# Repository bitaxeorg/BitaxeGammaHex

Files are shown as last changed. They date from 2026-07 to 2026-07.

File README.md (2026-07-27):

# Bitaxe Gamma Hex

Bitaxe Gamma Hex 1300 is a 6x BM1370 Open Source Bitcoin miner using [esp-miner](https://github.com/bitaxeorg/esp-miner). This project aims to provide a high-performance, energy-efficient Bitcoin mining solution using modern ASIC hardware.

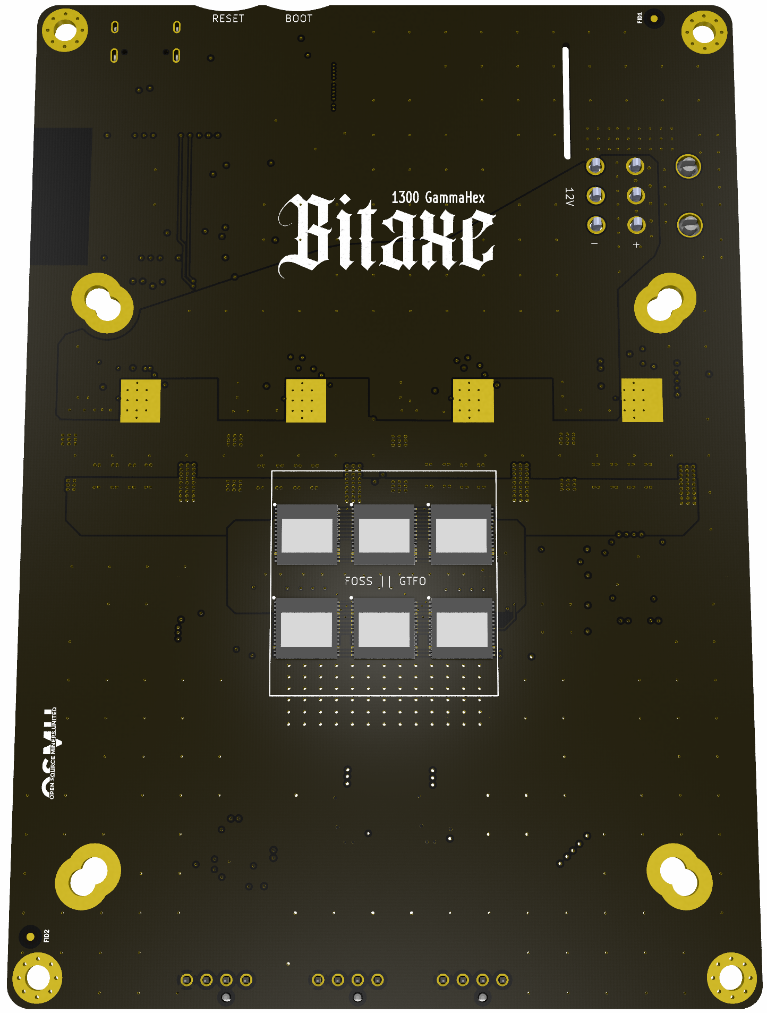
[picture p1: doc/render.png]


## Features

- 1.9 inch color LCD for mining stats.
- ESP32-S3 WiFi microcontroller with full [esp-miner](https://github.com/bitaxeorg/esp-miner) support.
- 12V Input via 6-pin molex.
- Six BM1370 arranged as 2 domains of 3 ASICs ech.
- Four phase TPS546D24S Voltage regulator with adjustable output and live telemetry.
- 12V Bitaxe Accessory Port
- EMC2103 Fan Controller and dual ASIC temp monitor.

## Contributing

BitaxeGammaHex is designed with [KiCad](https://kicad.org) open source PCB design suite. To contribute, follow these steps:

1. Fork the repository.
2. Create a new branch for your feature or bug fix:
   ```bash
   git checkout -b feature/your-feature-name
   ```
3. Make your changes and commit them:
   ```bash
   git commit -m "Add your commit message here"
   ```
4. Push your changes to your fork:
   ```bash
   git push origin feature/your-feature-name
   ```
5. Create a pull request on the main repository.

## License

This project is licensed under the CERN-OHL-2-S License - see the [LICENSE](LICENSE) file for details.

## Acknowledgments

We would like to acknowledge the following projects and individuals for their contributions to the Bitaxe Gamma Hex:

- [esp-miner](https://github.com/bitaxeorg/esp-miner) for the mining firmware.
- The [Open Source Miners United](https://osmu.xyz) community for their support and contributions.

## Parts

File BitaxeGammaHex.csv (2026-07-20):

Reference | Value | Footprint | Datasheet | Qty | PARTNO | Voltage | Exclude from BOM | Exclude from Board
R41,R48,R49,R50,R51,R67 | 0 | Resistor_SMD:R_0402_1005Metric |  | 6 | RC0402JR-070RL
C18,C38,C67,C71 | 33pF | Capacitor_SMD:C_0402_1005Metric | https://datasheets.kyocera-avx.com/C0GNP0-KGM.pdf | 4 | KGM05ACG1E330JH | 25V
C53,C72,C102,C110,C118,C134,C138 | 100pF | Capacitor_SMD:C_0402_1005Metric | https://datasheets.kyocera-avx.com/C0GNP0-KGM.pdf,https://datasheets.kyocera-avx.com/KGM_X7R.pdf | 7 | CC0402JRNPO9BN101 | 50V
C201,C202 | 470pF | Capacitor_SMD:C_0402_1005Metric | https://datasheets.kyocera-avx.com/KGM_X7R.pdf | 2 | GRM1555C1H471JA01D
C17,C37,C65,C68 | 1000pF | Capacitor_SMD:C_0805_2012Metric | https://www.yageo.com/upload/media/product/productsearch/datasheet/mlcc/UPY-GPHC_X7R_6.3V-to-250V_24.pdf | 4 | CC0805KRX7R9BB102 | 50V
C6,C99,C104,C142 | 2.2nF | Capacitor_SMD:C_0402_1005Metric | https://search.murata.co.jp/Ceramy/image/img/A01X/G101/ENG/GRM155R61H222KA01-01.pdf | 4 | GRM155R61H222KA01D | 25V
C5,C95,C101,C107 | 4.7nF | Capacitor_SMD:C_0402_1005Metric | https://search.murata.co.jp/Ceramy/image/img/A01X/G101/ENG/GRM155R71E472KA01-01.pdf | 4 | GRM155R71E472KA01D | 25V
C20,C40 | 33nf | Capacitor_SMD:C_0402_1005Metric |  | 2 | GCM155R71E333KA55D
C16,C36,C39,C64,C66,C83,C84,C203,C205,C206 | 0.1uF | Capacitor_SMD:C_0402_1005Metric | https://datasheets.kyocera-avx.com/KGM_X7R.pdf | 10 | KGM05AR71C104KH
C19,C22,C25,C42,C45,C106,C115,C129,C135,C141 | 100nf | Capacitor_SMD:C_0402_1005Metric |  | 10 | GRM188R61E106KA73D
L1,L2,L3,L4 | 270nH | bitaxe:SLC1175-271MEC_COC |  | 4 | SLC1175-121MEC
C4,C12,C14,C15,C29,C33,C35,C47,C55,C60,C62,C63,C85,C86,C87,C88,C89,C90,C91,C92,C93,C94,C96,C98,C111,C112,C113,C114,C119,C120,C121,C122,C123,C124,C125,C126,C127,C128,C131,C133,C143,C145,C147,C148,C153,C154,C155,C156,C157,C158,C159,C160,C161,C162,C163,C166,C171,C172,C177,C178,C179,C180,C181,C182,C183,C184,C185,C186,C187,C188,C189,C190,C191,C192,C193,C194,C195,C199,C200,C207 | 1uF | Capacitor_SMD:C_0402_1005Metric | https://mm.digikey.com/Volume0/opasdata/d220001/medias/docus/1117/EMK105BJ105MV-F_SS.pdf | 80 | CL05A105KO5NNNC | 25V
L5,L6 | 1.5uH | Inductor_SMD:L_Changjiang_FTC201612S | https://assets.ebee.com/datasheet/2512101426_cjiang-FTC201612S1R5MBCA_C5832350.pdf | 2 | FTC201612S1R5MBCA
C10,C26,C48,C57 | 4.7uF | Capacitor_SMD:C_0402_1005Metric | https://search.murata.co.jp/Ceramy/image/img/A01X/G101/ENG/GRM155R61A475MEAA-01.pdf | 4 | GRM155R61A475MEAAD
C49,C139,C140,C144,C146,C149,C150,C204,C208,C209 | 10uF | Capacitor_SMD:C_0603_1608Metric |  | 10 | GRM188R61E106KA73D | 25V
C7,C8,C9,C11,C13,C21,C23,C24,C27,C30,C41,C43,C44,C46,C50,C51,C52,C56,C58,C61,C77,C79,C97,C100,C108,C109,C116,C117,C130,C132,C136,C137 | 22uF | Capacitor_SMD:C_0805_2012Metric |  | 32 | CL21A226MAQNNNE
C69,C70,C73,C74,C75,C76,C80,C82,C103,C105,C151,C152,C164,C165,C167,C168 | 100uF | Capacitor_SMD:C_1206_3216Metric |  | 16 | CL31A107MQHNNNE | 6.3V
C28,C32 | 220uF | Capacitor_SMD:CP_Elec_8x10 |  | 2 | 118EC427
C31,C54,C78,C81 | 330uF | Capacitor_Tantalum_SMD:CP_EIA-7343-15_Kemet-W |  | 4 | ECG-SY0J331R | 6.3
R6,R9,R18,R19 | 1 | Resistor_SMD:R_0805_2012Metric | https://fscdn.rohm.com/en/products/databook/datasheet/passive/resistor/chip_resistor/esr-e.pdf | 4 | ESR10EZPJ1R0
R5,R8,R16,R17 | 10 | Resistor_SMD:R_0402_1005Metric | https://www.yageo.com/upload/media/product/products/datasheet/rchip/PYu-RC_Group_51_RoHS_L_12.pdf | 4 | RC0402FR-0710RL
R21,R22 | 49.9 | Resistor_SMD:R_0402_1005Metric | https://www.yageo.com/upload/media/product/products/datasheet/rchip/PYu-RC_Group_51_RoHS_L_12.pdf | 2 | RC0402FR-0749R9L
R25,R26,R32,R33,R38,R39,R55,R58,R61,R64,R68,R69,R70,R71,R72 | 1k | Resistor_SMD:R_0402_1005Metric |  | 15 | RC0402FR-071KL
R30,R31,R34,R35,R40 | 2k | Resistor_SMD:R_0402_1005Metric |  | 5 | RC0402FR-072KL
R12,R14,R15 | 4.7k | Resistor_SMD:R_0402_1005Metric |  | 3 | RC0402JR-074K7L
R44,R46 | 5.1k | Resistor_SMD:R_0402_1005Metric |  | 2 | RMCF0402JT5K10
R53 | 5.6k | Resistor_SMD:R_0402_1005Metric |  | 1 | RC0402FR-075K6L
R7,R10,R11,R13,R20,R24,R27,R42,R43,R45,R47,R52,R54,R56,R57,R59,R60,R62,R63,R65,R66,R73,R75,R78 | 10k | Resistor_SMD:R_0402_1005Metric | https://www.yageo.com/upload/media/product/products/datasheet/rchip/PYu-RC_Group_51_RoHS_L_12.pdf | 24 | RC0402DR-0710KL
R76 | 13.7k | Resistor_SMD:R_0402_1005Metric |  | 1 | RMCF0402FT13K7
R23 | 20k | Resistor_SMD:R_0402_1005Metric |  | 1 | RC0402FR-0720KL
R77 | 30.9k | Resistor_SMD:R_0402_1005Metric |  | 1 | RC0402FR-0730K9L
R74 | 52.3k | Resistor_SMD:R_0402_1005Metric |  | 1 | RC0402FR-0752K3L
U8,U9 | 25MHz | Oscillator:Oscillator_SMD_EuroQuartz_XO32-4Pin_3.2x2.5mm |  | 2 | SX3M25.000E20F30THN
U15 | AP2502KTR-G1 | Package_TO_SOT_SMD:SOT-23-6 | https://www.diodes.com/assets/Datasheets/AP2502.pdf | 1 | AP2502KTR-G1
A1,A2,A3,A4,A5,A6 | BM1370 | bitaxe:BM1370 |  | 6 | BM1370
J3,J6,J7 | Conn_01x04 | bitaxe:470531000 |  | 3 | 0470531000
J5 | Conn_02x03_Counter_Clockwise | bitaxe:MOLEX 39301060 |  | 1
U16 | EMC2103-2 | Package_DFN_QFN:QFN-16-1EP_4x4mm_P0.65mm_EP2.1x2.1mm | https://ww1.microchip.com/downloads/en/DeviceDoc/20005250.pdf | 1 | EMC2103-4-AP-TR
U14 | ESP32-S3-WROOM-1 | bitaxe:ESP32-S3-WROOM-1 | https://www.espressif.com/sites/default/files/documentation/esp32-s3-wroom-1_wroom-1u_datasheet_en.pdf | 1 | ESP32-S3-WROOM-1-N16R8
J2 | FPC-05F-30PH20 | bitaxe:FPC-SMD_30P-P0.50_XUNPU_FPC-05F-30PH20 |  | 1 | FPC-05FB-30PH20
U10,U11 | MCP1824T-1202E/OT | Package_TO_SOT_SMD:SOT-23-5 | https://ww1.microchip.com/downloads/en/DeviceDoc/22070a.pdf | 2 | MCP1824T-1202E/OT
U12,U13 | MCP1824T-0802E | Package_TO_SOT_SMD:SOT-23-5 | https://ww1.microchip.com/downloads/en/DeviceDoc/22070a.pdf | 2 | MCP1824T-0802E/OT
U7 | SN74AXC4T774 | Package_SO:TSSOP-16_4.4x5mm_P0.65mm | https://www.ti.com/lit/ds/symlink/sn74axc4t774.pdf | 1 | SN74AXC4T774PWR
SW1,SW2 | SWITCH-SPST | bitaxe:SW_TL3330AF130QG_EWI | https://configured-product-images.s3.amazonaws.com/Datasheets/TL3330.pdf | 2 | TL3330AF130QG
U17 | TLV3544 | Package_SO:TSSOP-14_4.4x5mm_P0.65mm | https://www.ti.com/lit/ds/symlink/tlv3542.pdf | 1 | TLV3544IPWR
U18,U19 | TPS62933 | Package_TO_SOT_SMD:SOT-583-8 | https://www.ti.com/lit/ds/symlink/tps62933.pdf | 2 | TPS62933DRLR
U3,U4,U5,U6 | TPS546D24S | bitaxe:LQFN40-CLIP | https://www.ti.com/lit/ds/symlink/tps546d24a.pdf | 4 | TPS546D24SRVFR
J1 | USB_C_Receptacle_USB2.0 | bitaxe:USB_C_Receptacle_GCT_USB4105-xx-A | https://www.usb.org/sites/default/files/documents/usb_type-c.zip | 1 | USB4105-GF-A

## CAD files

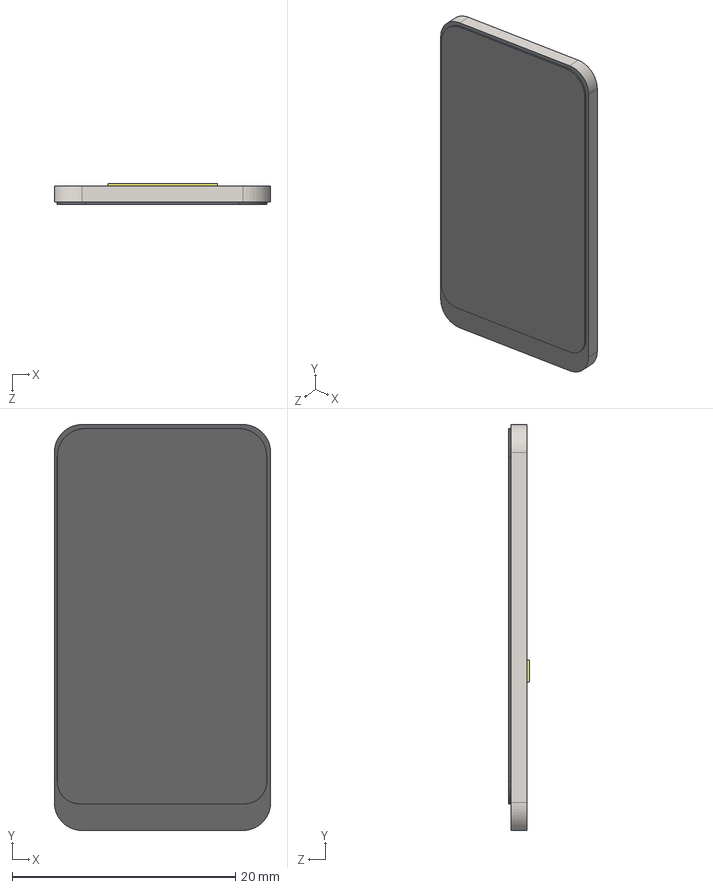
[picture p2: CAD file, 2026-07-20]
3d/DISST7789-176x320.STEP
19.4 x 36.4 x 1.86 mm

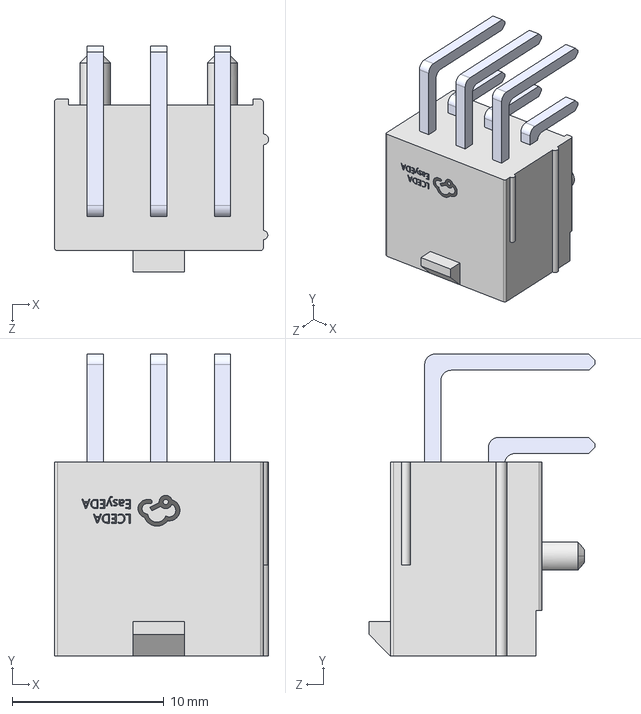
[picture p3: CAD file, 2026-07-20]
3dshapes/CONN-TN_39301060.step
14.2 x 19.9 x 14.9 mm

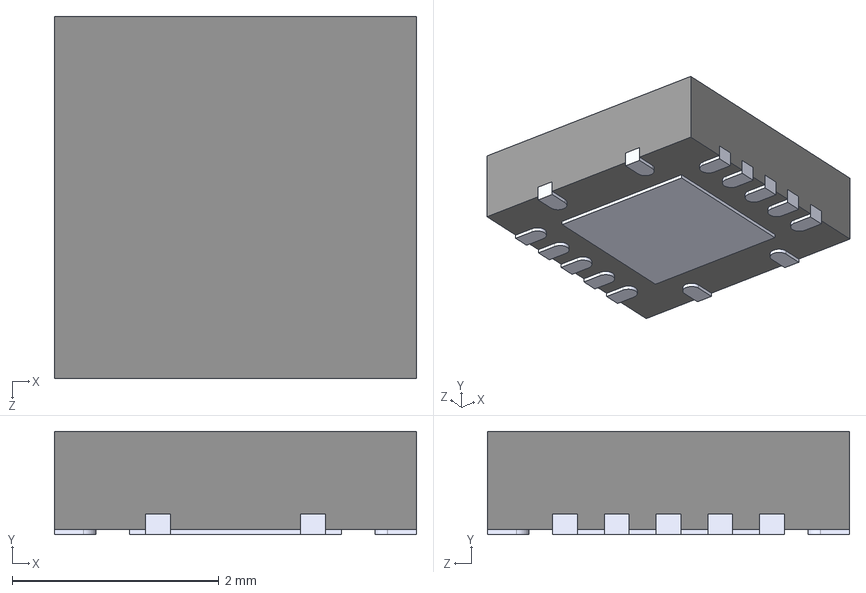
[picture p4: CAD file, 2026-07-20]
3d/TXB0104RGYR.STEP
3.50 x 1.00 x 3.50 mm

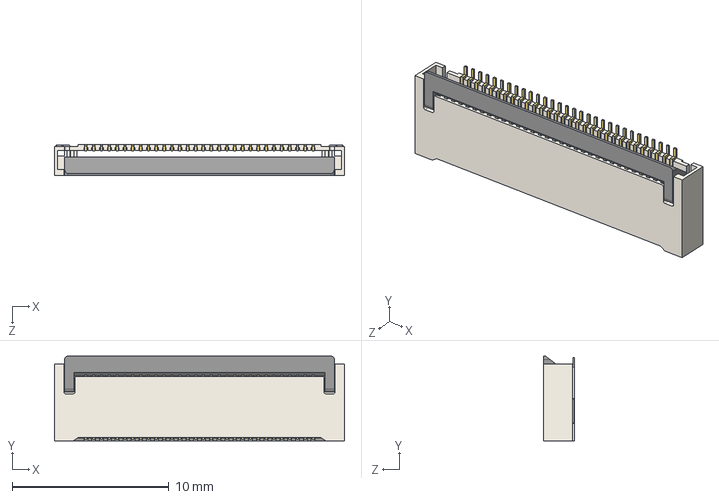
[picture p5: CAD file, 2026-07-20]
3dshapes/FPC-SMD_30P-P0.50_FPC-05FB-30PH20.step
18.5 x 5.40 x 2.00 mm

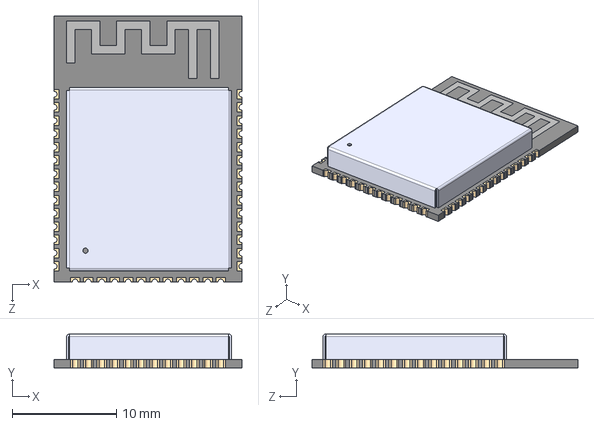
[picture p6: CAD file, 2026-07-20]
3d/ESP32-S3-WROOM-1-N8R2--3DModel-STEP-56544.STEP
18.0 x 3.25 x 25.5 mm

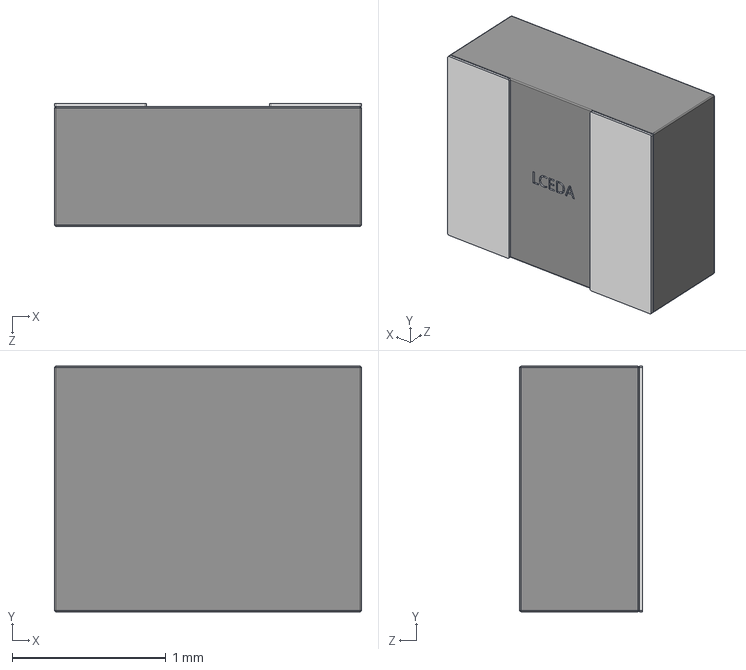
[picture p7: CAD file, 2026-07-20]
3dshapes/IND-SMD_L2.0-W1.6-B.step
2.00 x 1.60 x 0.8 mm

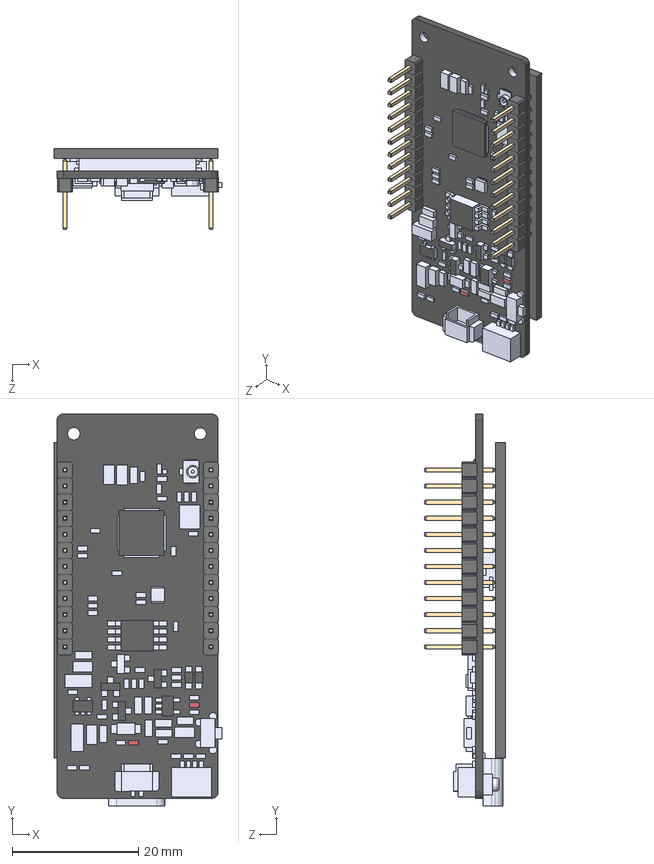
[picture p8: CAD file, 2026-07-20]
3d/T-Display-S3.STEP
26.5 x 62.0 x 12.9 mm
MainBoard_3D
Ecran
1_Male_Pin_2.54_mm x 24

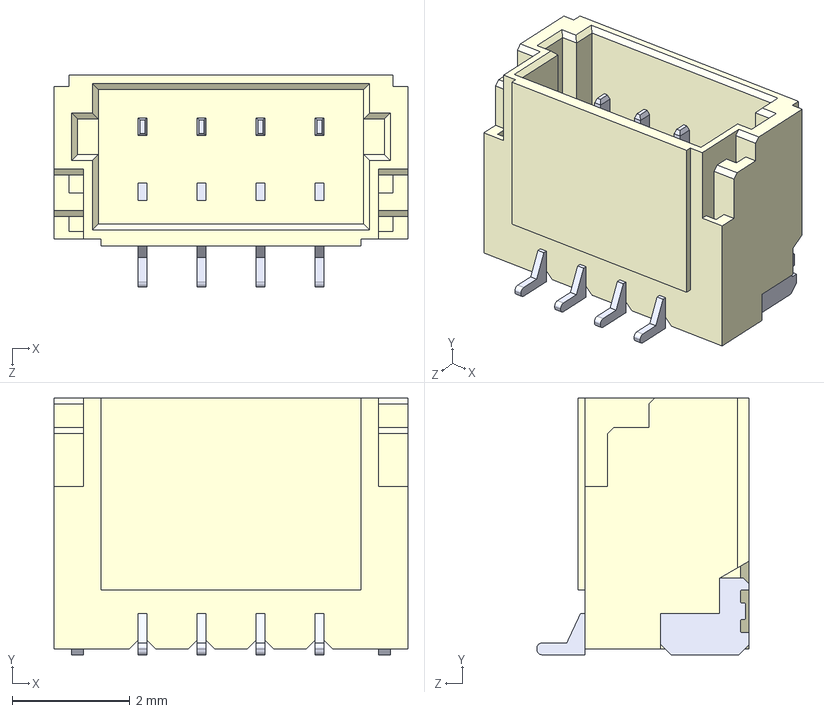
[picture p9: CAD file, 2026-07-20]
3d/BM04B-SRSS-TBT(LF)(SN)--3DModel-STEP-56544.STEP
6.00 x 4.35 x 3.60 mm

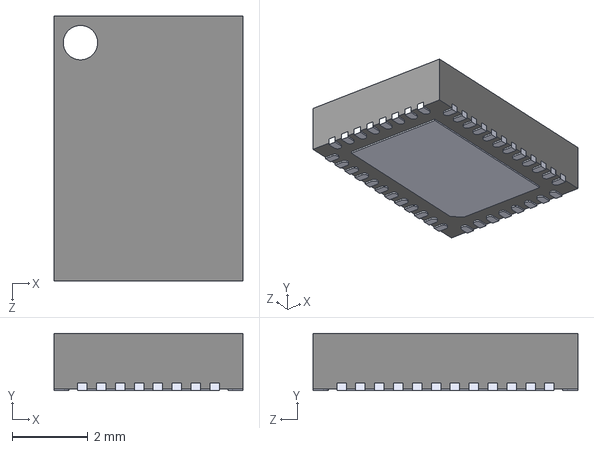
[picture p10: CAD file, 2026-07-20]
3d/TPS546D24ARVFR.step
5.00 x 1.52 x 7.00 mm

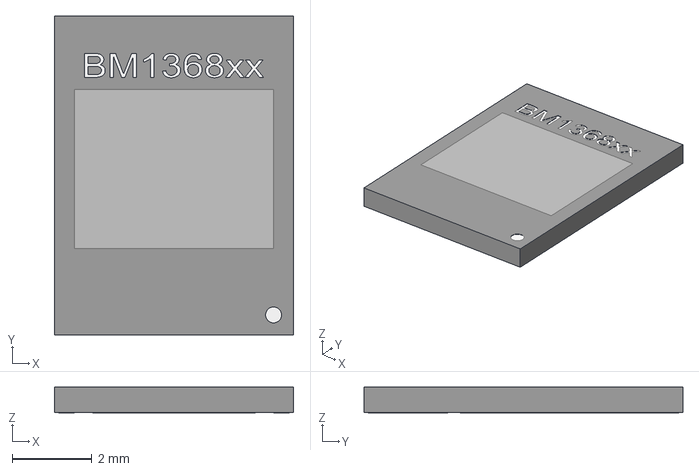
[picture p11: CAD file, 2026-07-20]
3d/BM1368xx.stp
6.00 x 8.00 x 0.65 mm

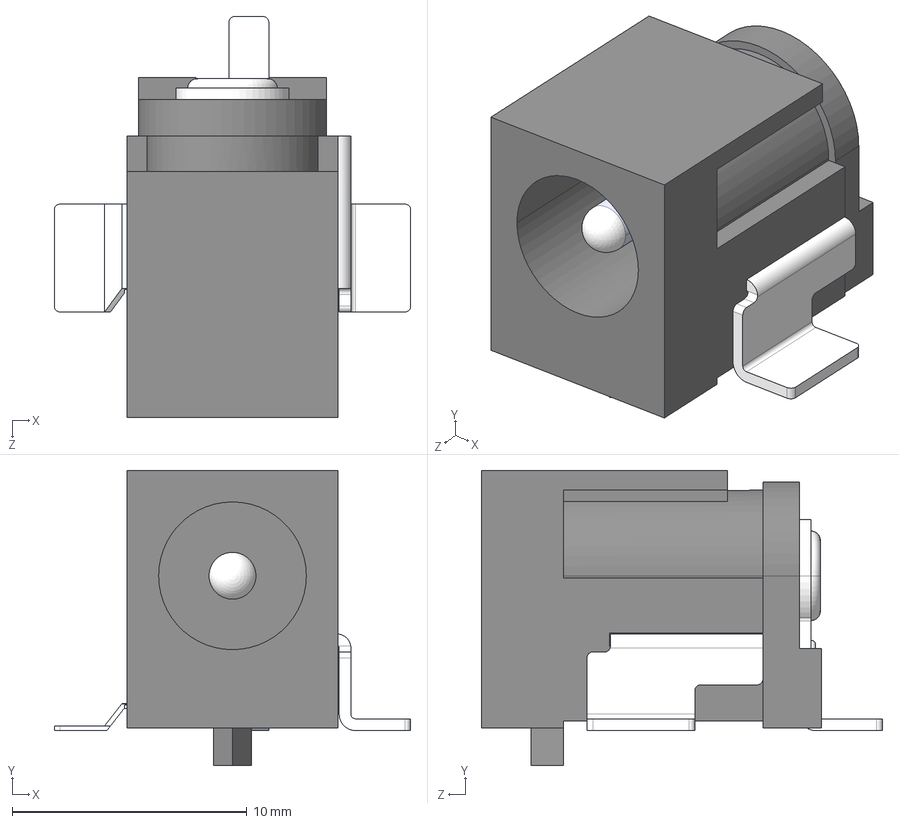
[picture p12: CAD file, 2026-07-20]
3d/CUI_DEVICES_PJ-036AH-SMT-TR.step
15.2 x 12.6 x 17.1 mm

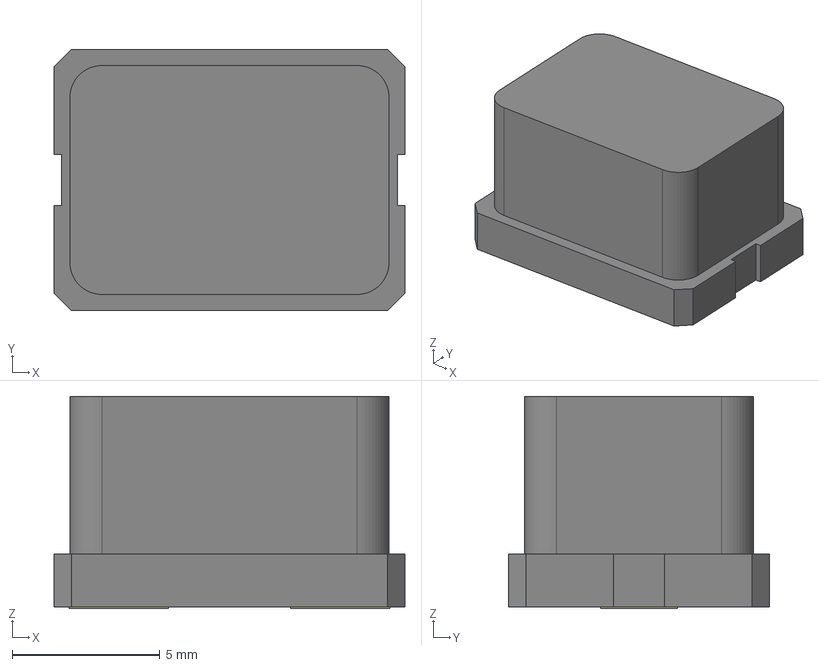
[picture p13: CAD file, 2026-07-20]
3d/SLC1175-271MEC_COC.step
11.9 x 8.83 x 7.19 mm

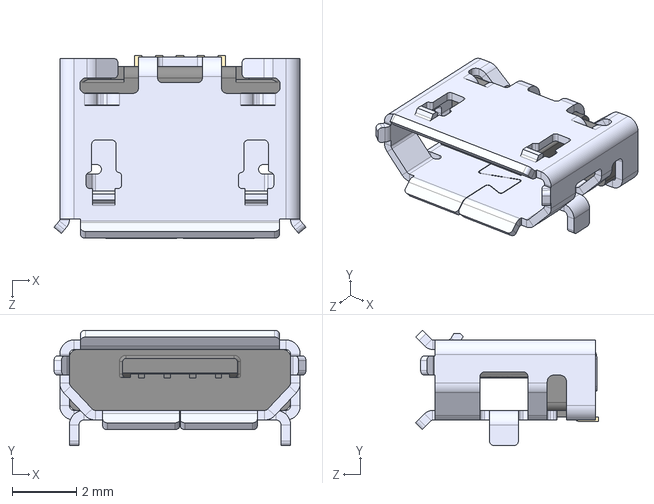
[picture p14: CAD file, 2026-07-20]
3d/USB_10118193-0001LF.STEP
7.86 x 3.60 x 5.71 mm

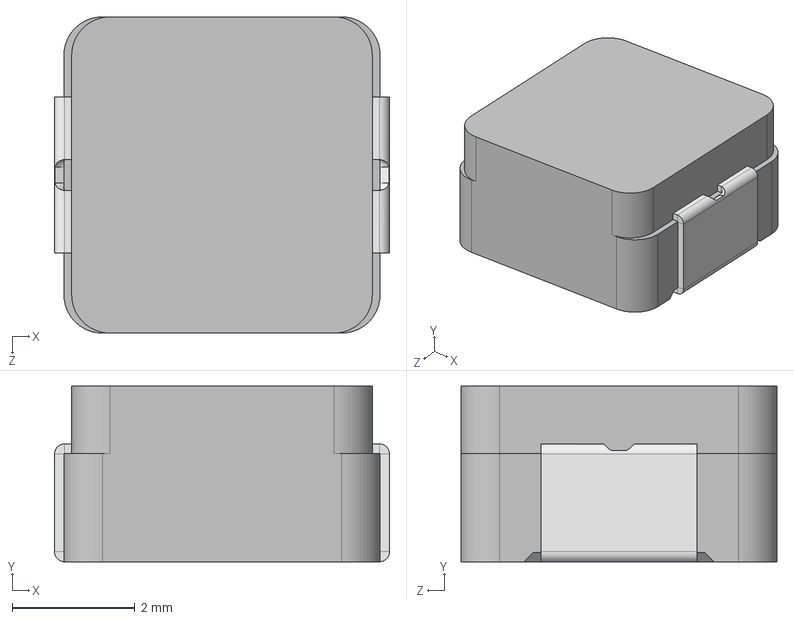
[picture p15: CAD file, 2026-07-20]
3d/IHLP2020CZ.step
5.45 x 2.86 x 5.15 mm

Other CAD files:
3d/Littelfuse 0154.500DRT without value_black v2.step
3d/TSOT-23-5_RIT.step
3d/DRC0010J.stp
3d/XTAL_SC32S-7PF20PPM_EPS.step
3d/bm1370.scad
3d/csd95472.scad
3d/141_TL3330AFxxxQG.stp
3d/21-0164B_L622-1_MXM.step
3d/2R5TPE220MAFB.step
3d/470531000.stp
3d/54-00164.STEP
3d/BQB0016A.stp
3d/Bitaxe_Heatsink.step
3d/CS1213AG-tr.stp
3d/CUI_DEVICES_PJ-002AH.step
3d/CUI_DEVICES_PJ-037AH.step
3d/CX3225SB16000H0FLJCC.STEP
3d/Coilcraft-SLC1175.STEP
3d/Cree_PLCC6.stp
3d/DCJ250-20-B-XX-X_REVA1.step
3d/DQG0008A.stp
3d/DQH0008A.stp
3d/DRL0006A.stp
3d/FP1006V2-R.STEP
3d/FTSH-105-01-F-DV-K.stp
3d/KMR231GLFS.stp
3d/OLED_0.91_128x32.stp
3d/PLCC6_LED_3_5X3_4X2_8_CRW.step
3d/SIS0011A.stp
3d/SMV_z90.stp
3d/SN74AXC1T45DBVR.STEP
3d/SOT-23-5_M5_MCH.step
3d/ST-4ETB2k_(202).stp
3d/SW_CS1213AGF260_CRS.step
3d/XRCGB27M120F3M10R0_MUR.step
3d/XT30PW-M.stp
3d/barrel-jack.step
3d/bm1366.step
3d/bm1370.step
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

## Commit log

2026-07-20 Bitaxe GammaHex hardware release
    [141_TL3330AFxxxQG.stp, 21-0164B_L622-1_MXM.step, 2R5TPE220MAFB.step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]
2026-07-27 update sheet hw version
    [BitaxeGammaHex.kicad_sch, asic.kicad_sch, esp32s3.kicad_sch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]
2026-07-27 fix KiCad trailing space warning
    [BitaxeGammaHex.kicad_sch, asic.kicad_sch, esp32s3.kicad_sch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]
2026-07-27 power sheet schematic cleanup
    [BitaxeGammaHex.kicad_sch, asic.kicad_sch, esp32s3.kicad_sch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]
